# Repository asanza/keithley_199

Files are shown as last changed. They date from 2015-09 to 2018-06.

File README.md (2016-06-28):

# Keithley 199 Digital Board Replacement

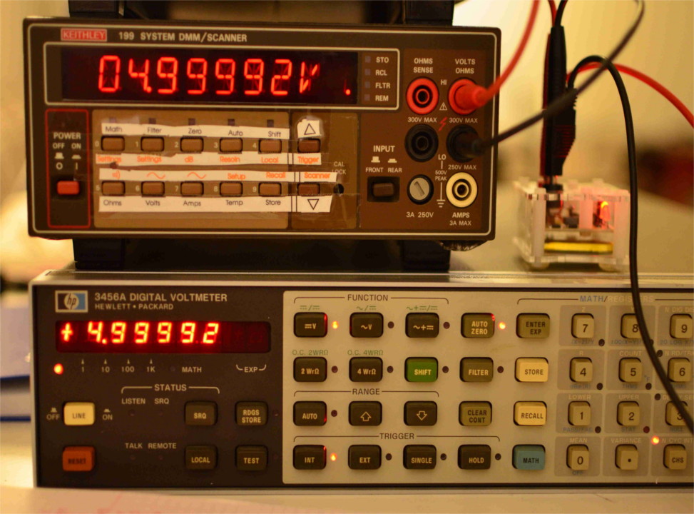
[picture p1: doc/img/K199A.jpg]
keithley 199


This is an upgrade replacement for the digital control board on Keithley 199 multimeters.

The [Keithley 199](doc/k199_op_maint.pdf) is a digital multimeter built in the nineties. It is capable of current, voltage and resistance measurements and also provides a gpib interface for remote control.

These multimeters contains three electronic circuit boards, one which contains the analog circuitry, including analog signal conditioning and analog digital converter, a display board which contains the user interface, and a digital control board, with a processor who controls display, gpib interface and analog digital converter.

This repository contains hardware and software files needed to build a replacement of the digital control board.

# Features
- Voltage Measurement 0.3, 3, 30, 300 VDC/VAC 6.5 digits
- Current Measurement 30mA, 3A DC/AC,  6.5 digits
- Resistance Measurement 300-3GOhm, 6.5 digits, 4 wire.
- Arbitrary integration period
- SCPI interface
- Free Software

# Building the hardware 

The hardware files are in [Kicad](http://kicad-pcb.org/) format. Gerber files are (not yet) available.

# Building the software

The software was built with the [Microchip Toolchain](http://www.microchip.com/mplab/compilers). 

We use [Ceedling](http://www.throwtheswitch.org/ceedling/) for building and testing (but for comfort, [MPLABX](http://www.microchip.com/mplab/mplab-x-ide) files are available). 

In order to build the software, go to the root directory and do:

```
$rake release

```
Or to perform the unit tests:
```
$rake test:all
```

## Hardware

The hardware is pretty basic. It contains a pic32mx controller which do the heavy lifting. An ftdi chip provides an usb interface, while two open drain drivers controll the led displays. The external trigger input and output are connected to the microcontroller through the necessary input/output protection.

## Calibration

TODO

## Principles of Operation

The interesting part is the Control of the analog board. The analog board contains a series of switches that are controlled with a shift register. The adc conversion is performed with a discrete charge-balance adc which returns a pulse train with a pulse count proportional to the input voltage. The control of the adc is performed by the microcontroller in the digital board and should observe a precise timing in order to guarantee adc accuracy.

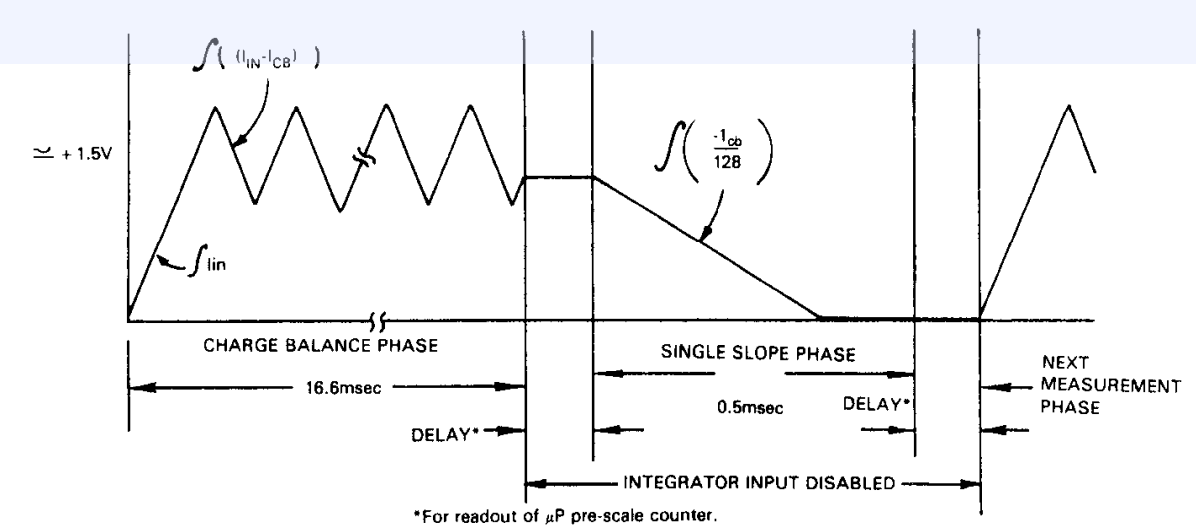
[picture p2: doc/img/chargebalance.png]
charge balance


As shown in the figure above, the charge balance phase starts after the controller sends a start of conversion to the analog board. While the charge balance phase takes place, the controller counts the number of pulses it receives from the analog board. The analog board only send pulses on the up parts, thus the number of pulses is proportional to the charge acumulated. After exactly 16.66 msecs the controller sends an stop of conversion and the single slope phase starts, discharging the integrator. While discharge takes place, the controller counts the number of pulses received.

# Licence

```
 * Copyright (c) 2015, Diego F. Asanza. All rights reserved.
 *
 * This software is free software; you can redistribute it and/or
 * modify it under the terms of the GNU Lesser General Public
 * License as published by the Free Software Foundation; either
 * version 2.1 of the License, or (at your option) any later version.
 *
 * This library is distributed in the hope that it will be useful,
 * but WITHOUT ANY WARRANTY; without even the implied warranty of
 * MERCHANTABILITY or FITNESS FOR A PARTICULAR PURPOSE.  See the GNU
 * Lesser General Public License for more details.
 *
 * You should have received a copy of the GNU Lesser General Public
 * License along with this library; if not, write to the Free Software
 * Foundation, Inc., 51 Franklin Street, Fifth Floor, Boston,
 * MA 02110-1301  USA
 *
 ```

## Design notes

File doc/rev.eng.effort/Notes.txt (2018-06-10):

Data is shifted in Positive clock Transitions. (It means data is valid on trailing edge (negative transition)
Data is received INVERTED in analog board (the optocoupler inverts).
Strobe shifts data to out. Strobe is also inverted in analog board.

5 bytes are sended each time (there are 5 shift registers, four on analog board and one on scanner card.). The last byte controls the analog digital converter.

Last Register Bits: (Digital Board)
Seq.	Q8	Q7	Q6	Q5		Q4	Q3		Q2	Q1	Time
	/Cal	/Zero	Fast	/ReadSwitch	Sig	/FinalSlope	Sync	Int
0x95	1	0	0	1		0	1		0	1	6m  // Start integration
0x94	1	0	0	1		0	1		0	0	20m // end integration
0x92	1	0	0	1		0	0		1	0	0   // Rundown slope	

0x55	0	1	0	1		0	1		0	1	6m  // Start Integration
0x54	0	1	0	1		0	1		0	0	20m  // end integration
0x52	0	1	0	1		0	0		1	0	800u // Rundown slope

Cal: When 0 is the reference connected to the A/D
Zero: When 0  the multiplexer selects ground for input to the A/D
Fast:
ReadSwitch: When 0 in Analog board, the position of front/rear switch is readed (-4.3 and volts/ohms lo)
Sig: When 1 in analog board, 3V signal direct to A/D
/FinalSlope:	Starts the Rundown slope integration
Sync: Resets AD Clocks
Int: (Start Conversion)

The conversion sequence is as follows. 

- Integration Vin
- Integration Vin Zero
- Integration Vref
- Integration Vref Zero

Vout = -2.8*(Vin - VinZero)/(Vref - VrefZero)

30 V requeriments requerew a separate zero

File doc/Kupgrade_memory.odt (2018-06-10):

Keithley Repair memory

Start: 12 March 2014

Recently I bought an old Keithley 199 multimeter in an auction at e-bay. It didn't work, but it was cheap. Further analysis showed an error on the digital board. The VIA (peripheral controller) was broken.

I know, I could bough a new via (they are no more produced, I think, but they are still available from resellers on e-bay). But, as an engineer, that solution wasn't satisfactory. I wanted to bring the old multimeter to new standards (at least in the digital side). So with a lot of naivety, I decided to replace the broken board with my own creation.

Actually, the good think with old measurement equipment, is that almost all good manufacturers published pretty detailed service manuals, schematic inclusive. Paraphrasing Feynman, to have the map of the cat is the best form to start.

The Digital interface couldn't be more simple. In order to reduce the number of control lines between digital and analog boards, the Keithley 199 uses a serial interface. Pretty basic, nothing to fancy like spi or i2c. Three control lines go from digital to analog board and one goes back into the digital world. The firs three are serial data which are clocked into shift registers in the analog board, which in turn, control the different switch for range selection, ohms measurements, and analog digital conversion. The line which goes back provides the digital value of the analog signal, the output of the analog digital converter.

Well, this in theory. Now it is time to go into the finer details. One thing, which I personally find fascinating, is that the analog digital converter is actually implemented with discrete parts, and actually controlled from the processor. Nowadays this is no more done, as there is frequently a custom ASIC or an FPGA who does the control of the integrating analog digital converter.

The analog digital converter is from the charge-balancing variety. In order to explain how it works, may be is easier to start with a close cousin, the double ramp integrating analog to digital converter.

The double ramp integrating converter, as it name hints, works integrating the unknown voltage for a fixed amount of time, and then discharging the integration capacitor connecting a reference voltage of opposite polarity and measuring the time the output of the integrator takes to reach zero. This process is shown graphically on figure x. It shows a basic integrator circuit where the voltage output ramps up as function of the unknow voltage and time. The relationship between unknown voltage and time is given by following formula:

In the ramp down part, an know reference voltage, of reverse polarity as the input signal, is connected to the input. The output voltaje ramps down until it reach zero. The output voltage during this ramp down period is given by following formula:

Relating equations 1 and 2, we can calculate the input voltage as function of the time passed between start of the ramp up period and end of the ramp down period:

Easy, isn't it. At least in theory. But as always the devil is in the details. We will talk about this in a moment.

The double ramp converter is easy to implement, and as we can see in formula x, it is almost independent of the actual phisical components. And I say almost, because even thought the values of the components are left out of the equation, this equation assumes ideal integrator behavior in first place. And, oh surprise, it is not!.

The first problem is related to the limited supply voltage. The integrator is, of course, an electronic circuit, and it needs to get its supply voltage from somewhere. If we let connected the unknown voltage at the input of the integrator (see figure x), the output voltage will ramp-up but only until the output voltage reaches nearly the supply voltage, a situation know as saturation.

The second problem comes from the integrating capacitor. I know, it comes a little bit of a surprise, because there is no capacitor in the equation for the output voltage (eq. y), but remember from which equations it comes from:

1 y 2

Did you see?. When you equal these two equations in order to get the output voltage, you make the assumption that the capacitor in the interval one is the same that is on interval two, and it is not always the case. Due to a phenomenon know as “Dielectric absorption”, the capacitor will change its behavior with time.

Here comes the charge balancing in the game. Charge balancing works similar as double slope, first an unknown voltage is integrated, but instead of let the output go indefinite up, a circuit compares the output and when it reaches a defined level, and then, a reference voltage is applied in the input which causes the output to ramp down. When the output voltage has ramp down for a little while, we disconnect again the reference voltage, which causes the output to ramp up again, as the unknown voltage is still present in the input. If we track carefully how much time has the output voltage ramped down, we can also calculate the unknown input voltage.

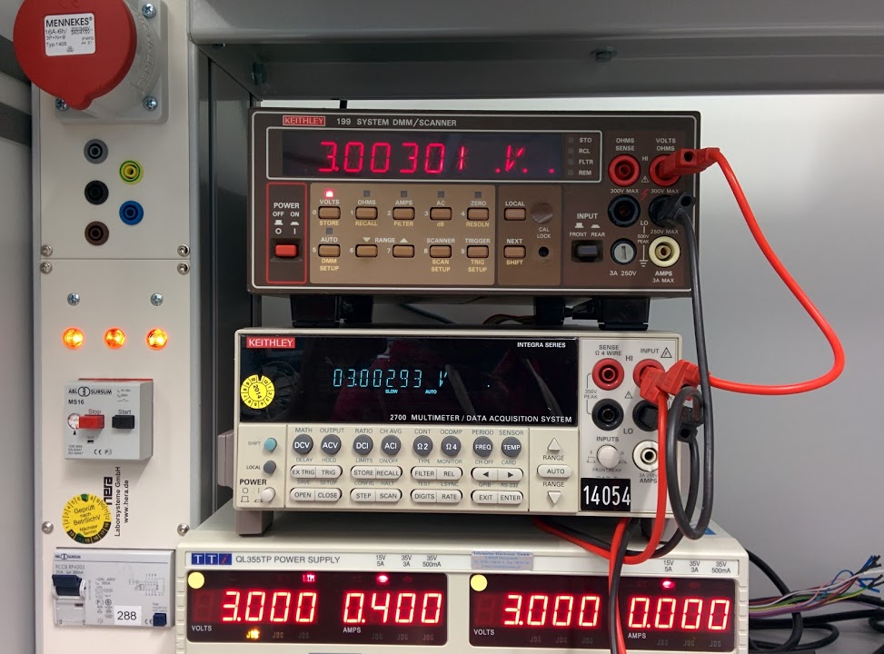
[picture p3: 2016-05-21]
doc/img/K199_back.jpg

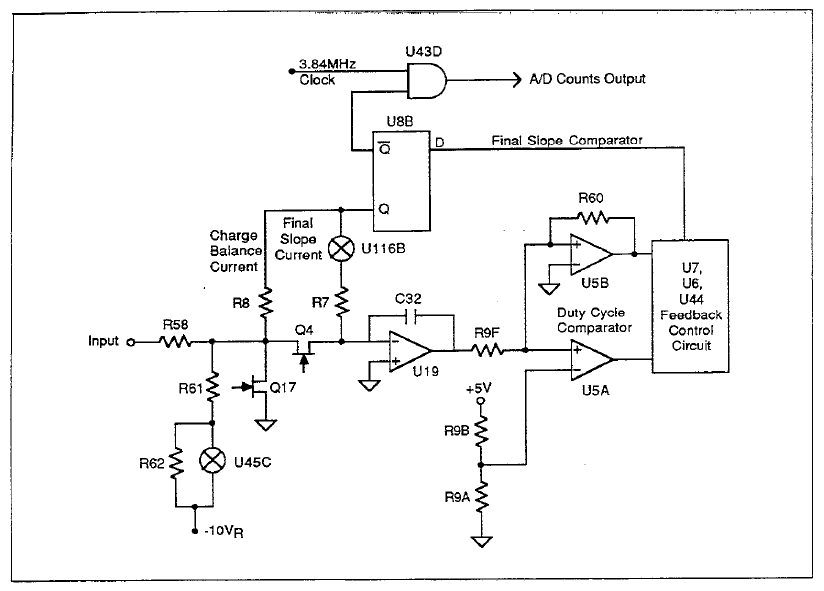
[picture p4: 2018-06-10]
doc/keithley_adc_sch.png

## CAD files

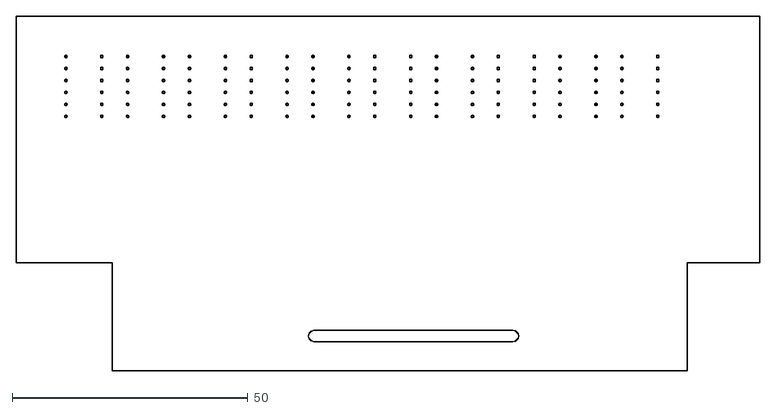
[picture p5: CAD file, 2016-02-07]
hw.kicad/frontpanel/frontpanel.dxf
157.7 x 75.2

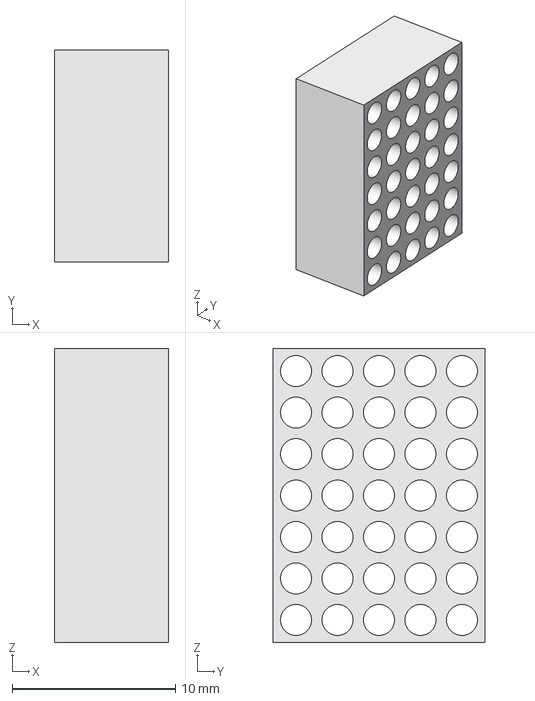
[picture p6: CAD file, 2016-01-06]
hw.kicad/frontpanel/LedMatrix.fcstd
7.00 x 13.0 x 18.0 mm

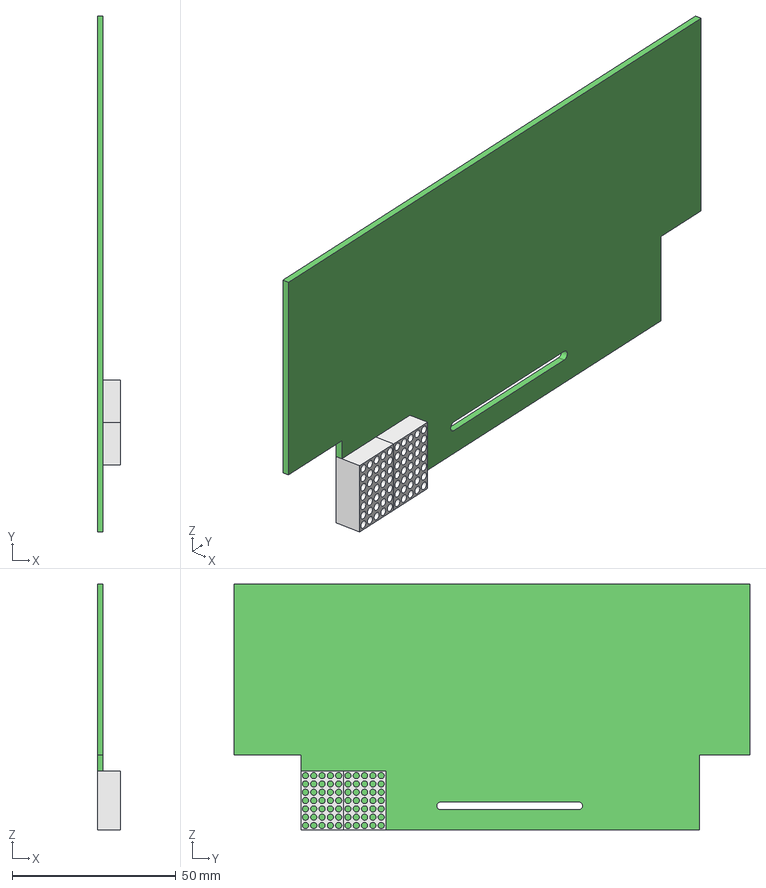
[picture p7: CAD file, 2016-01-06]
hw.kicad/frontpanel/frontdesign.fcstd
7.00 x 157.7 x 75.2 mm
pcb

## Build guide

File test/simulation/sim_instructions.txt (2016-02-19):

device pic32MX350F256H
hwtool sim
set oscillator.auxfrequency 	120
set oscillator.auxfrequencyunit Mega
set oscillator.frequency 	100
set oscillator.frequencyunit 	Mega
set oscillator.rcfrequency  	250
set oscillator.rcfrequencyunit 	Kilo
set uart2io.uartioenabled	true
set uart2io.output		file
set uart2io.outputfile		test/simulation/out.txt
set system.disableerrormsg 	true

program build/test/TestBuild.elf

run
break unity.c:1168
wait 20000
quit

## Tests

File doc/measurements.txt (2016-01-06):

#2015-12-08 09:43:34.418110
1; +0.2499589E+01; +02.49944E+0; 0.000149
2; +0.2499550E+01; +02.49940E+0; 0.00015
3; +0.2499591E+01; +02.49949E+0; 0.000101
4; +0.2499580E+01; +02.49943E+0; 0.00015
5; +0.2499571E+01; +02.49944E+0; 0.000131
6; +0.2499570E+01; +02.49943E+0; 0.00014
7; +0.2499559E+01; +02.49943E+0; 0.000129
8; +0.2499611E+01; +02.49943E+0; 0.000181
9; +0.2499579E+01; +02.49945E+0; 0.000129
10; +0.2499560E+01; +02.49942E+0; 0.00014
11; +0.2499571E+01; +02.49944E+0; 0.000131
12; +0.2499582E+01; +02.49943E+0; 0.000152
13; +0.2499551E+01; +02.49944E+0; 0.000111
14; +0.2499601E+01; +02.49944E+0; 0.000161
15; +0.2499583E+01; +02.49944E+0; 0.000143
16; +0.2499602E+01; +02.49945E+0; 0.000152
17; +0.2499581E+01; +02.49946E+0; 0.000121
18; +0.2499560E+01; +02.49943E+0; 0.00013
19; +0.2499601E+01; +02.49945E+0; 0.000151
20; +0.2499591E+01; +02.49942E+0; 0.000171
21; +0.2499540E+01; +02.49943E+0; 0.00011
22; +0.2499590E+01; +02.49946E+0; 0.00013
23; +0.2499590E+01; +02.49944E+0; 0.00015
24; +0.2499541E+01; +02.49942E+0; 0.000121
25; +0.2499570E+01; +02.49942E+0; 0.00015
26; +0.2499572E+01; +02.49945E+0; 0.000122
27; +0.2499570E+01; +02.49944E+0; 0.00013
28; +0.2499571E+01; +02.49946E+0; 0.000111
29; +0.2499571E+01; +02.49946E+0; 0.000111
30; +0.2499560E+01; +02.49946E+0; 9.99999999998e-05
31; +0.2499571E+01; +02.49943E+0; 0.000141
32; +0.2499559E+01; +02.49946E+0; 9.90000000001e-05
33; +0.2499572E+01; +02.49948E+0; 9.2e-05
34; +0.2499571E+01; +02.49945E+0; 0.000121
35; +0.2499582E+01; +02.49942E+0; 0.000162
36; +0.2499582E+01; +02.49941E+0; 0.000172
37; +0.2499593E+01; +02.49941E+0; 0.000183
38; +0.2499593E+01; +02.49942E+0; 0.000173
39; +0.2499591E+01; +02.49939E+0; 0.000201
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

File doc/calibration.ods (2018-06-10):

Ref | Test | a | b | corrected
0.004 | 0.000136 | 0.0283305456 | 0.003996147 | 0.004
0.6 | 21.0375 |  |  | 0.6

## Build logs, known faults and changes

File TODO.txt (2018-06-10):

- Revisar FTDI Pinout (which type??)
- Look out for a LDO 3.3V (http://www.ti.com/lit/ds/symlink/lm2936.pdf)
- Xtal (8MHz) footprint (type, condensators)    //DONE
- EEPROM (Need code)                            
- Display drivers (or transistors)              
- Trigger Input and Voltmeter complete (outputs) voltmeter complete can be used for other signals also (square wave, pulse, pwm, etc)
- Look for resistor networks (80 and 4k7 (10k))
- Look for ftdi circuit

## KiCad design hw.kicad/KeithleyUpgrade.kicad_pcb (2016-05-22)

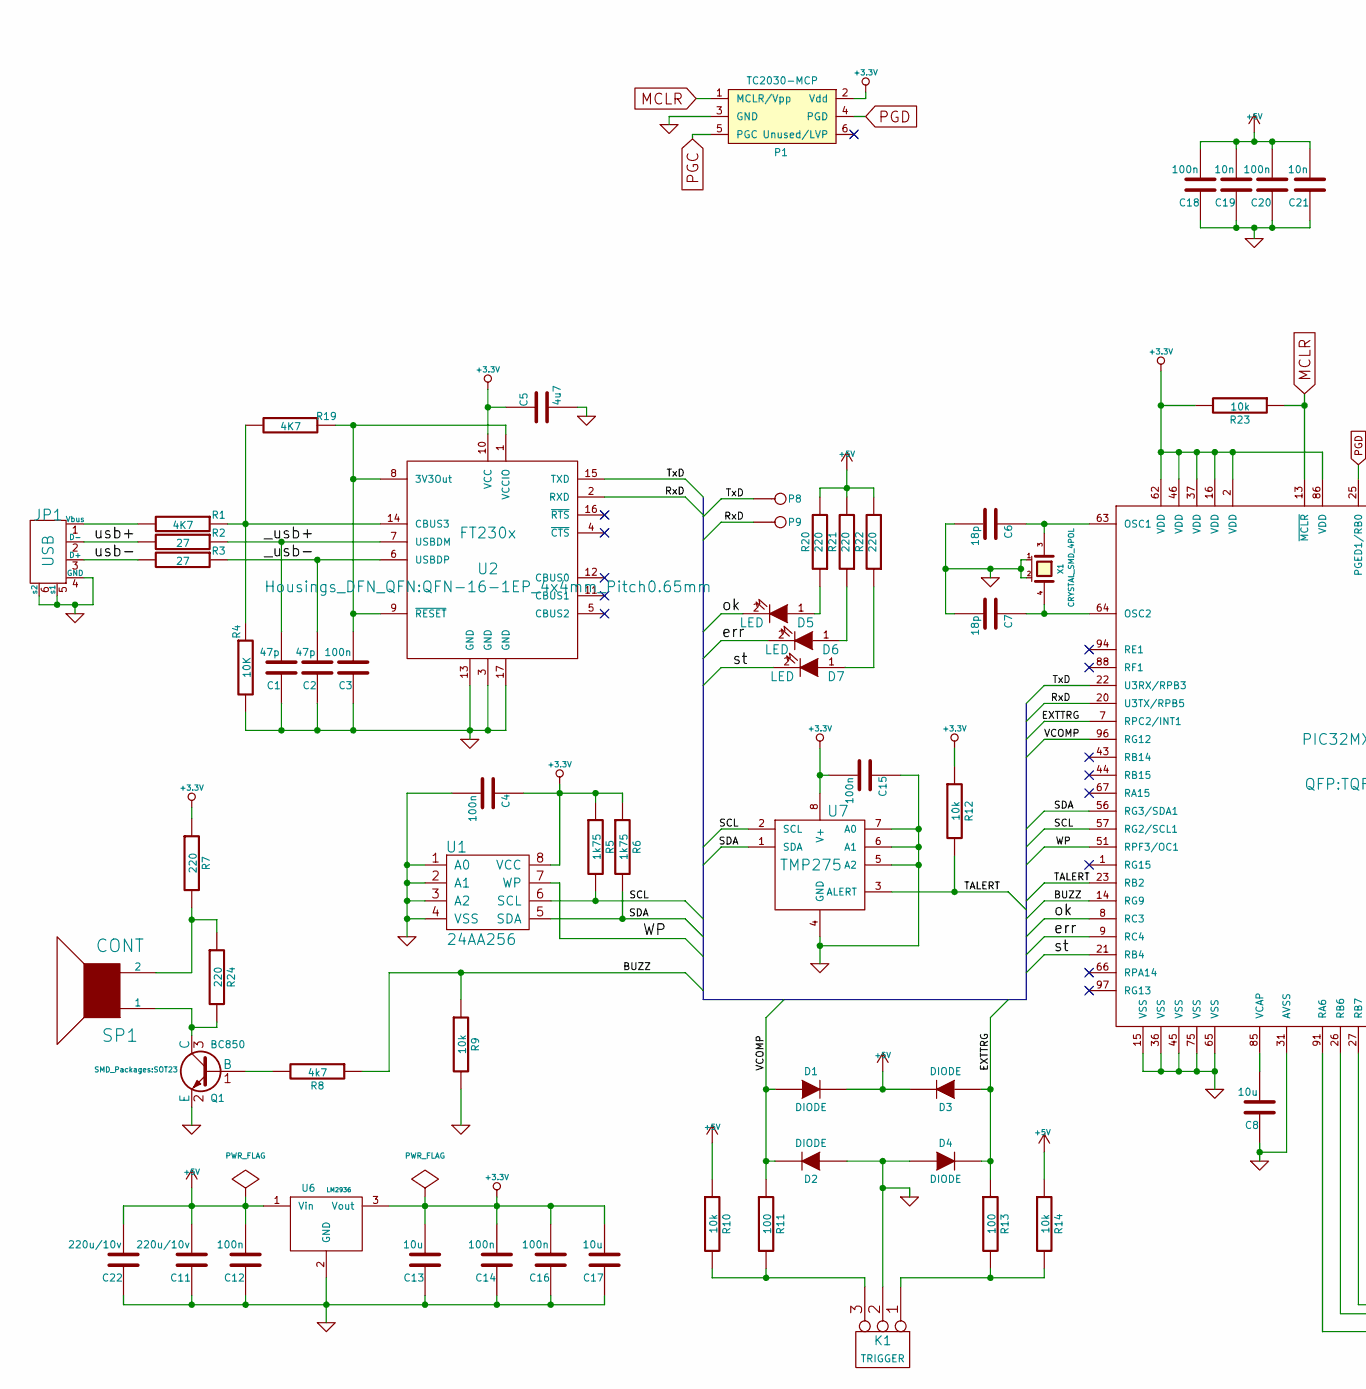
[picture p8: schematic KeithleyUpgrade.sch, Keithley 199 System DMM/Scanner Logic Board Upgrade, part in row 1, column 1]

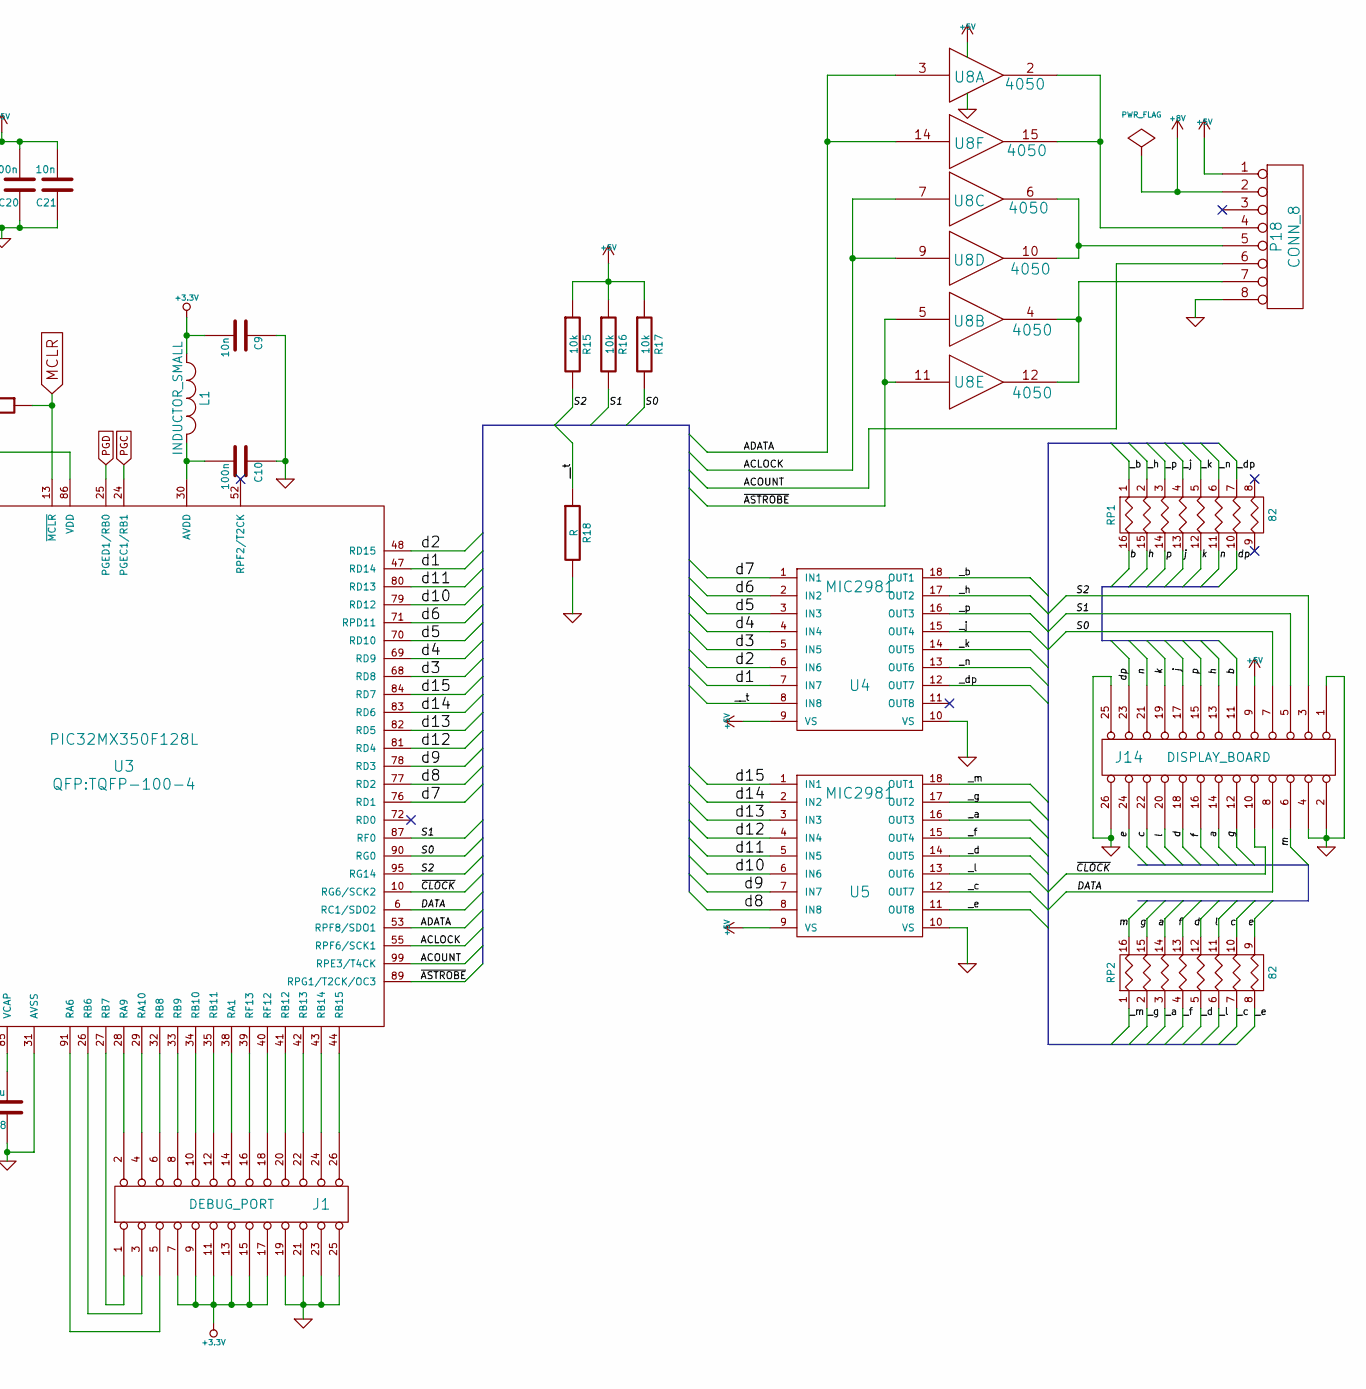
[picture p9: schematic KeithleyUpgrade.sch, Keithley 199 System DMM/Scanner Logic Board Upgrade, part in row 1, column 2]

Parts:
C1, C2: 47p; C_0805
C3, C4, C10, C12, C14, C15, C16, C18, C20: 100n; C_0805
C5: 4u7; C_1206
C6, C7: 18p; C_0805
C8: 10u; C_0805
C9, C19, C21: 10n; C_0805
C11, C22: 220u/10v; c_elec_10x10
C13, C17: 10u; C_1210
D1, D2, D3, D4: DIODE; Diode-SMA_Standard
D5, D6, D7: LED; LED-0805
J1: DEBUG_PORT; header_straight_2x13
J14: DISPLAY_BOARD; header_straight_2x13
JP1: USB; USB_B
K1: TRIGGER; bornier3
L1: INDUCTOR_SMALL; SMD-1210
P1: TC2030-MCP; TC2030-NL_SMALL
P8, P9: TP1; SIL-1
P18: CONN_8; Pin_Header_Straight_1x08
Q1: BC850; SOT23
R1: 4K7; SM0805
R2, R3: 27; SM0805
R4: 10K; SM0805
R5, R6: 1k75; SM0805
R7: 220; SM0805
R8: 4k7; SM0805
R9, R10, R12, R14, R15, R16, R17, R23: 10k; R_0805
R11, R13: 100; R_0805
R18: R; R_0805
R19: 4K7; R_0805
R20, R21, R22, R24: 220; R_0805
RP1, RP2: 82; SOM16
SP1: CONT; Elko_vert_DM14_RM5
U1: 24AA256; SOIC-8_N
U2: FT230x; QFN-16-1EP_4x4mm_Pitch0.65mm
U3: PIC32MX350F128L; TQFP-100-4
U4, U5: MIC2981; soic-18
U6: LM2936; DPAK2
U7: TMP275; SOIC-8_N
U8: 4050; SOIC-16_Narrow
X1: CRYSTAL_SMD_4POL; XTAL_SMD_5x3_2

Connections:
/ACLOCK: U3.55 (RPF6/SCK1), U8.7, U8.9
/ACOUNT: P18.6, U3.99 (RPE3/T4CK)
/ADATA: U3.53 (RPF8/SDO1), U8.3, U8.14
/BUZZ: R8.1, R9.1, U3.14 (RG9)
/DATA: J14.8, U3.6 (RC1/SDO2)
/EXTTRG: D3.1 (A), D4.2 (K), R13.1, U3.7 (RPC2/INT1)
/RxD: P9.1, U2.2 (RXD), U3.20 (U3TX/RPB5)
/S0: J14.7, R17.2, U3.90 (RG0)
/S1: J14.5, R16.2, U3.87 (RF0)
/S2: J14.3, R15.2, U3.95 (RG14)
/SCL: R5.2, U1.6 (SCL), U3.57 (RG2/SCL1), U7.2 (SCL)
/SDA: R6.2, U1.5 (SDA), U3.56 (RG3/SDA1), U7.1 (SDA)
/TALERT: R12.2, U3.23 (RB2), U7.3 (ALERT)
/TxD: P8.1, U2.15 (TXD), U3.22 (U3RX/RPB3)
/VCOMP: D1.1 (A), D2.2 (K), R11.1, U3.96 (RG12)
/WP: U1.7 (WP), U3.51 (RPF3/OC1)
/__t: R18.1, U4.8 (IN8)
/_a: RP2.3, U5.16 (OUT3)
/_b: RP1.1, U4.18 (OUT1)
/_c: RP2.7, U5.12 (OUT7)
/_d: RP2.5, U5.14 (OUT5)
/_dp: RP1.7, U4.12 (OUT7)
/_e: RP2.8, U5.11 (OUT8)
/_f: RP2.4, U5.15 (OUT4)
/_g: RP2.2, U5.17 (OUT2)
/_h: RP1.2, U4.17 (OUT2)
/_j: RP1.4, U4.15 (OUT4)
/_k: RP1.5, U4.14 (OUT5)
/_l: RP2.6, U5.13 (OUT6)
/_m: RP2.1, U5.18 (OUT1)
/_n: RP1.6, U4.13 (OUT6)
/_p: RP1.3, U4.16 (OUT3)
/_usb+: C1.2, R2.1, U2.7 (USBDM)
/_usb-: C2.2, R3.1, U2.6 (USBDP)
/a: J14.14, RP2.14 (R3)
/b: J14.11, RP1.16 (R1)
/c: J14.22, RP2.10 (R7)
/d: J14.18, RP2.12 (R5)
/d1: U3.47 (RD14), U4.7 (IN7)
/d2: U3.48 (RD15), U4.6 (IN6)
/d3: U3.68 (RD8), U4.5 (IN5)
/d4: U3.69 (RD9), U4.4 (IN4)
/d5: U3.70 (RD10), U4.3 (IN3)
/d6: U3.71 (RPD11), U4.2 (IN2)
/d7: U3.76 (RD1), U4.1 (IN1)
/d8: U3.77 (RD2), U5.8 (IN8)
/d9: U3.78 (RD3), U5.7 (IN7)
/d10: U3.79 (RD12), U5.6 (IN6)
/d11: U3.80 (RD13), U5.5 (IN5)
/d12: U3.81 (RD4), U5.4 (IN4)
/d13: U3.82 (RD5), U5.3 (IN3)
/d14: U3.83 (RD6), U5.2 (IN2)
/d15: U3.84 (RD7), U5.1 (IN1)
/dp: J14.23, RP1.10 (R7)
/e: J14.24 (P20), RP2.9 (R8)
/err: D6.2 (K), U3.9 (RC4)
/f: J14.16, RP2.13 (R4)
/g: J14.12, RP2.15 (R2)
/h: J14.13, RP1.15 (R2)
/j: J14.17, RP1.13 (R4)
/k: J14.19, RP1.12 (R5)
/l: J14.20, RP2.11 (R6)
/m: J14.6, RP2.16 (R1)
/n: J14.21, RP1.11 (R6)
/ok: D5.2 (K), U3.8 (RC3)
/p: J14.15, RP1.14 (R3)
/st: D7.2 (K), U3.21 (RB4)
/usb+: JP1.2 (D-), R2.2
/usb-: JP1.3 (D+), R3.2
/~ASTROBE: U3.89 (RPG1/T2CK/OC3), U8.5, U8.11
/~CLOCK: J14.10, U3.10 (RG6/SCK2)
GND: C1.1, C2.1, C3.1, C4.2, C5.2, C6.2, C7.2, C8.1, C9.1, C10.1, C11.1, C12.1, C13.1, C14.1, C15.1, C16.1, C17.1, C18.1, C19.1, C20.1, C21.1, C22.1, D2.1 (A), D4.1 (A), J1.19, J1.21, J1.23, J1.25 (P24), J14.1, J14.2, J14.4, J14.25 (P24), J14.26 (P22), JP1.4 (GND), JP1.5 (s1), JP1.6 (s2), K1.2 (PM), P1.3 (GND), P18.8, Q1.2 (E), R4.2, R9.2, R18.2, U1.1 (A0), U1.2 (A1), U1.3 (A2), U1.4 (VSS), U2.3 (GND), U2.13 (GND), U2.17 (GND), U3.15 (VSS), U3.31 (AVSS), U3.36 (VSS), U3.45 (VSS), U3.65 (VSS), U3.75 (VSS), U4.10 (VS), U5.10 (VS), U6.2 (GND), U7.4 (GND), U7.5 (A2), U7.6 (A1), U7.7 (A0), U8.8 (VSS), X1.1 (case), X1.2 (case)
MCLR: P1.1 (MCLR/Vpp), R23.1, U3.13 (~MCLR)
unnamed: C3.2, R19.1, U2.1 (VCCIO), U2.8 (3V3Out), U2.9 (~RESET)
unnamed: C6.1, U3.63 (OSC1), X1.3
unnamed: C7.1, U3.64 (OSC2), X1.4
unnamed: C8.2, U3.85 (VCAP)
unnamed: C10.2, L1.2, U3.30 (AVDD)
unnamed: D5.1 (A), R20.1
unnamed: D6.1 (A), R21.1
unnamed: D7.1 (A), R22.1
unnamed: J1.1, U3.27 (RB7)
unnamed: J1.2, U3.28 (RA9)
unnamed: J1.3, U3.26 (RB6)
unnamed: J1.4, U3.29 (RA10)
unnamed: J1.5, U3.91 (RA6)
unnamed: J1.6, U3.32 (RB8)
unnamed: J1.8, U3.33 (RB9)
unnamed: J1.10, U3.34 (RB10)
unnamed: J1.12, U3.35 (RB11)
unnamed: J1.14, U3.38 (RA1)
unnamed: J1.16, U3.39 (RF13)
unnamed: J1.18, U3.40 (RF12)
unnamed: J1.20, U3.41 (RB12)
unnamed: J1.22, U3.42 (RB13)
unnamed: JP1.1 (Vbus), R1.2
unnamed: K1.1, R13.2, R14.2
unnamed: K1.3, R10.2, R11.2
unnamed: P18.4, U8.2, U8.15
unnamed: P18.5, U8.6, U8.10
unnamed: P18.7, U8.4, U8.12
unnamed: Q1.1 (B), R8.2
unnamed: Q1.3 (C), R24.2, SP1.1
unnamed: R1.1, R4.1, R19.2, U2.14 (CBUS3)
unnamed: R7.2, R24.1, SP1.2
PGC: P1.5 (PGC), U3.24 (PGEC1/RB1)
PGD: P1.4 (PGD), U3.25 (PGED1/RB0)

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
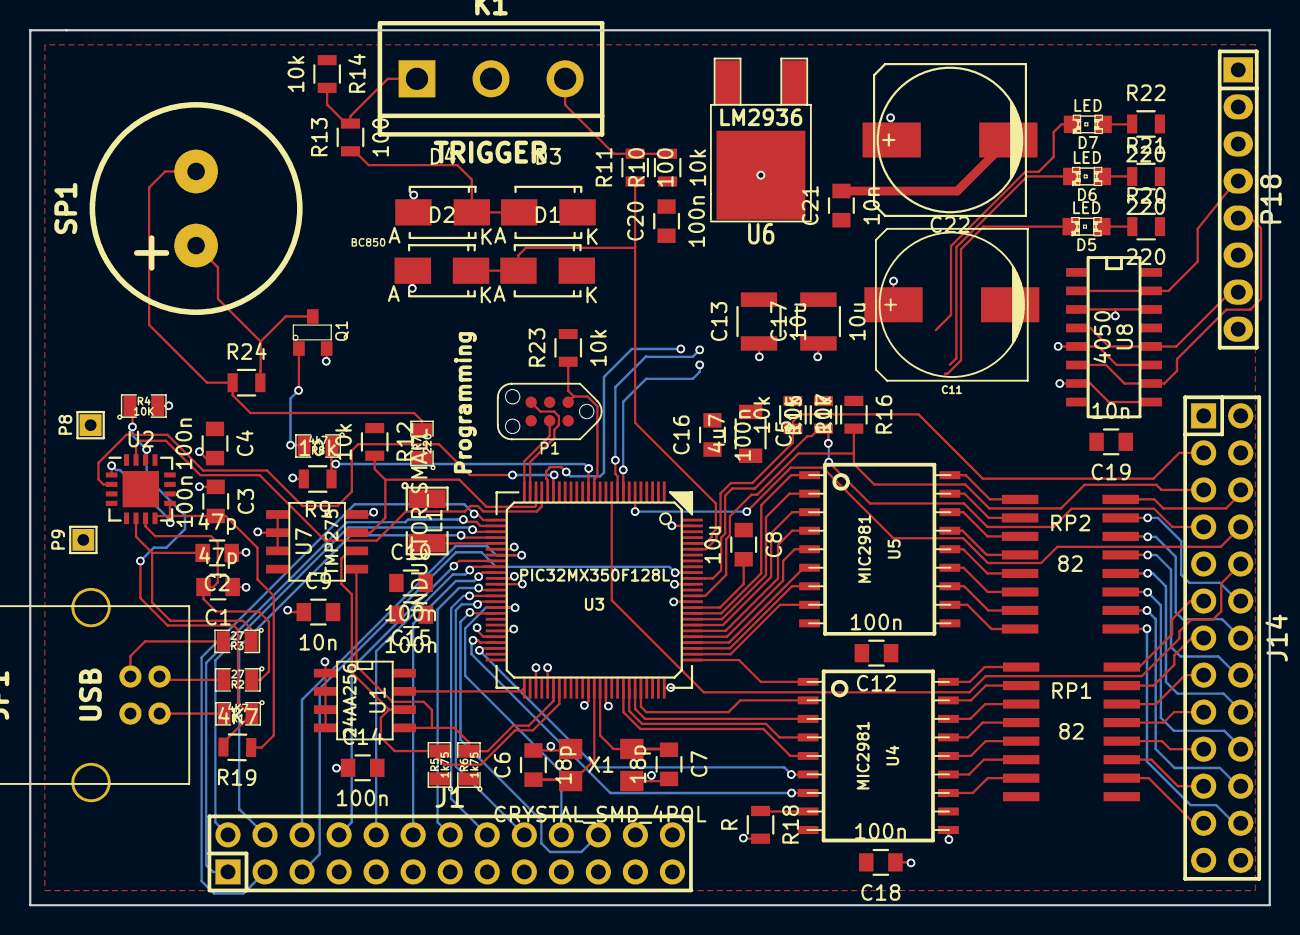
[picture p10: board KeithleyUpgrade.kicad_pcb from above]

Board: 4 copper layers, 85.0 x 60.0 mm, 75 parts (0 on the bottom side), 109 nets.

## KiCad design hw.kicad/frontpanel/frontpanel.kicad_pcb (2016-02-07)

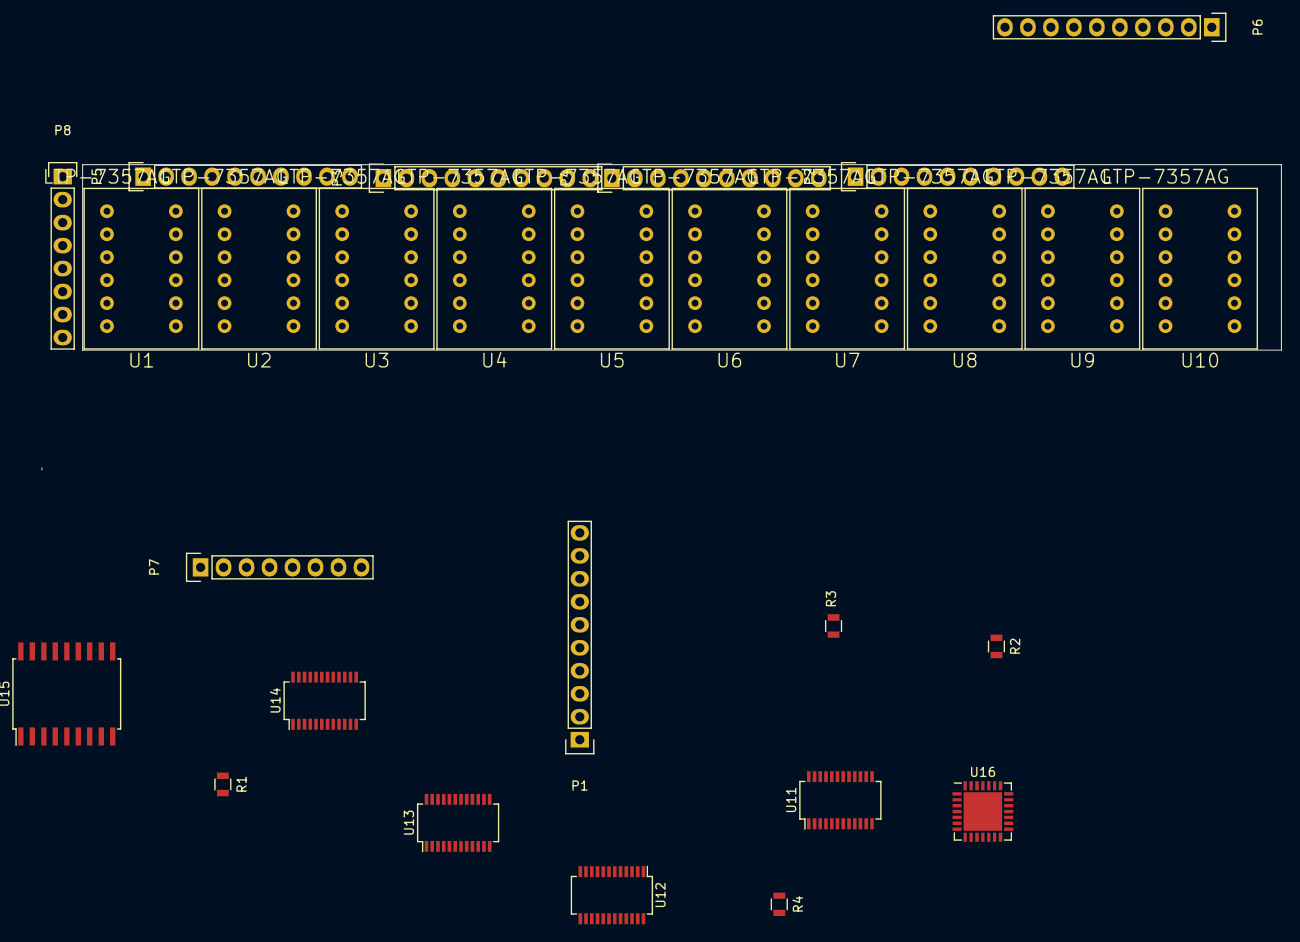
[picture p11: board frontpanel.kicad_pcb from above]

Board: 2 copper layers, 28 parts (0 on the bottom side), 19 nets, no tracks yet.

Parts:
P1, P2, P3, P4, P5, P6: CONN_10; Pin_Header_Straight_1x10
P7, P8: CONN_8; Pin_Header_Straight_1x08
R1, R2, R3, R4: R; R_0805
U1, U2, U3, U4, U5, U6, U7, U8, U9, U10: LTP-7357AG
U11, U12, U13, U14: TLC5928; SSOP-24_3.9x8.7mm_Pitch0.635mm
U15: MIC2981; SOIC-18_7.5x11.6mm_Pitch1.27mm
U16: DSPIC33FJ64GP802; QFN-28-1EP_6x6mm_Pitch0.65mm

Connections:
/ROW1: U1.12, U2.12, U3.12, U4.12, U5.12, U6.12, U7.12, U8.12, U9.12, U10.12
/ROW2: U1.11, U2.11, U3.11, U4.11, U5.11, U6.11, U7.11, U8.11, U9.11, U10.11
/ROW3: U1.2, U2.2, U3.2, U4.2, U5.2, U6.2, U7.2, U8.2, U9.2, U10.2
/ROW4: U1.9, U2.9, U3.9, U4.9, U5.9, U6.9, U7.9, U8.9, U9.9, U10.9
/ROW5: U1.4, U2.4, U3.4, U4.4, U5.4, U6.4, U7.4, U8.4, U9.4, U10.4
/ROW6: U1.5, U2.5, U3.5, U4.5, U5.5, U6.5, U7.5, U8.5, U9.5, U10.5
/ROW7: U1.6, U2.6, U3.6, U4.6, U5.6, U6.6, U7.6, U8.6, U9.6, U10.6
GND: R1.2, R2.2, R3.2, R4.2, U11.1, U12.1, U13.1, U14.1, U15.10
unnamed: R1.1, U14.23
unnamed: R2.1, U11.23
unnamed: R3.1, U12.23
unnamed: R4.1, U13.23
unnamed: U11.2, U12.22
unnamed: U11.3, U12.3, U13.3, U14.2
unnamed: U11.4, U12.4, U13.4, U14.3
unnamed: U11.21, U12.21, U13.21, U14.4
unnamed: U12.2, U13.22
unnamed: U13.2, U14.22
VCC: U11.24, U12.24, U13.24, U14.24, U15.9

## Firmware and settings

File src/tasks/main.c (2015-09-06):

#include <stdio.h>
#include <diag.h>
#include <FreeRTOS.h>
#include <task.h>
#include <assert.h>
#include <system.h>
#include <diag.h>
#include "tskmgr.h"

int main()
{
    /* hardware initialization. An error here is unrecoverable */
    system_init();
    /* start tasks as needed */
    taskmgr_start();
    DIAG("START: %s, %s", REPOVERSION, REPOBRANCH);
    DIAG("Starting Scheduler");
    vTaskStartScheduler();
    return 0;
}

void vAssertCalled(const char* fileName, unsigned long lineNo)
{
    DIAG("FreeRTOS: %s, %ld\n", fileName, lineNo);
    while (1);
}

void vApplicationIdleHook(void)
{
    hal_sys_idle();
}

void vApplicationStackOverflowHook(TaskHandle_t pxTask, signed char *pcTaskName)
{
    DIAG("%s", pcTaskName);
    assert(0);
    while (1);
}

void vApplicationMallocFailedHook()
{
    DIAG("");
    assert(0);
    while (1);
}

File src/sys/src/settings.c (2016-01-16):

/*
 * store.c
 *
 * Copyright (c) 2015, Diego F. Asanza. All rights reserved.
 *
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
 * Created on July 15, 2015, 10:39 PM
 */

#include "settings.h"
#include <eefs.h>
#include <stdbool.h>

#include "adcctrl.h"
#include <FreeRTOS.h>
#include "semphr.h"
#include "portmacro.h"
#include <assert.h>
#include <string.h>
#include <diag.h>
#include <math.h>
#include <adcdefs.h>

typedef struct _settings_t{
    adc_input               input               :4 ; /* settings name */
    adc_channel             channel             :8 ; /* which channel is selected on the scanner */
    adc_integration_period  integration_period  :16; /* integration period used */
    adc_range               range               :4 ; /* selected range */
    adc_resolution          resn                :3 ;
    bool                    auto_range          :1 ; /* auto_range selected */
    bool                    filter_enabled      :1 ; /* filter */
    uint8_t                 filter_resoln       :8 ; /* filter resolution */
    conv_func               math;                    /* selected math function */
    out_fmt                 formatter;               /* selected output format */
} __attribute__((__packed__)) settings_t;

typedef struct _calibration_t{
    double gain;
    double offset;
    double temp;
}calibration_t;

#define SETTINGS_START_ADDRESS  0x0A
static calibration_t cal;

SemaphoreHandle_t slock = NULL;

static void lock(void){
    xSemaphoreTake(slock, portMAX_DELAY);
}

static void unlock(void){
    xSemaphoreGive(slock);
}

/* each input has its settings */
static settings_t settings[ADC_NUMBER_OF_INPUTS];
static settings_t* actual_settings = settings;

static void settings_set_default();

void settings_init(void){
    if(!slock){
        slock = xSemaphoreCreateMutex();
    }
    int i;    
    for (i = 0; i < ADC_NUMBER_OF_INPUTS; i++) {
        settings_set_default();
    }
    cal.gain = 1;
    cal.offset = 0;
    cal.temp = 25;
}

void settings_save(settings_location location){
    lock();
    int i;
    int addr = SETTINGS_START_ADDRESS + location*sizeof(settings);
    for(i = 0; i < ADC_NUMBER_OF_INPUTS; i++)
        eefs_object_save(addr + i,&settings[i], sizeof(settings_t));
    eefs_object_save(addr + i, &actual_settings, sizeof(settings_t*));
    unlock();
}

adc_resolution settings_get_resolution(){
    adc_resolution res;
    lock();
    res = actual_settings->resn;
    unlock();
    return res;
}

void settings_set_resolution(adc_resolution res){
    lock();
    if(actual_settings->input == ADC_INPUT_TEMP) 
        actual_settings->resn = ADC_RESOLUTION_5_5;
    else
        actual_settings->resn = res;
    unlock();
}


int settings_restore(settings_location location) {
    int i;
    lock();
    EEFS_ERROR err;
    DIAG(" %d\n", 0);
    int addr = SETTINGS_START_ADDRESS + location * sizeof (settings);
    for (i = 0; i < ADC_NUMBER_OF_INPUTS; i++) {
        err = eefs_object_restore(addr + i, &settings[i], sizeof (settings_t));
        DIAG("iperiod: %d", settings[i].integration_period);
        if (err != EEFS_OK) {
            DIAG("error loading settings");
            settings_set_default();
            unlock();
            return 1;
        }
    }
    actual_settings = settings;
    DIAG("");
//    err = eefs_object_restore(addr + i, &actual_settings, sizeof(settings_t*));
//    if(err != EEFS_OK){
//        actual_settings = settings;
//        DIAG("error loading actual setting");
//    }
    unlock();
    return 0;
}

adc_integration_period settings_get_integration_period(){
    adc_integration_period p;
    lock();
    p = actual_settings->integration_period;
    unlock();
    return p;
}

adc_input settings_get_input(){
    adc_input p;
    lock();
    p = actual_settings->input;
    unlock();
    return p;
}

adc_range settings_get_range(){
    adc_range r;
    lock();
    r = actual_settings->range;
    unlock();
    return r;
}

adc_channel settings_get_channel(){
    lock();
    adc_channel c = actual_settings->channel;
    unlock();
    return c;
}

void settings_set_input(adc_input input){
    assert(input < ADC_NUMBER_OF_INPUTS);
    lock();
    actual_settings = &settings[input];
    unlock();
}

void settings_range_up(void){
    lock();
    if(actual_settings->input == ADC_INPUT_TEMP){
        unlock();
        return;
    }
    /* get the next range for this input */
    adc_range range = adcctrl_get_next_range(actual_settings->input, actual_settings->range);
    if(range == actual_settings->range){
        unlock();
        return;
    }
    actual_settings->range = range;
    unlock();
}

void settings_range_down(void){
    lock();
    if(actual_settings->input == ADC_INPUT_TEMP){
        unlock();
        return;
    }
    adc_range range = adcctrl_get_previous_range(actual_settings->input, actual_settings->range);
    if(range == actual_settings->range){
        unlock();
        return;
    }
    actual_settings->range = range;
    unlock();
}
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

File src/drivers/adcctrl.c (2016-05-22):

/*
 * adcctrl.c
 *
 * Copyright (c) 2015, Diego F. Asanza. All rights reserved.
 *
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
 * Created on July 15, 2015, 10:39 PM
 */

/* This file generates the integration sequences which are sended to analog
 * multiplexer in multimeter.
 * They where copied from another working Keithley 199.
 * (c) 2014 Diego F. Asanza
 */

#include <stdint.h>
#include <stddef.h>
#include <assert.h>
#include <diag.h>
#include "adcctrl.h"

struct hal_adc_integration_sequence_t {
    uint32_t actual_value;
    uint32_t size;
    const uint32_t* mux_values;
};

#define START_SEQUENCE(seq_name) static const uint32_t seq_name##__[]=

#define END_SEQUENCE(seq_name) ; static adc_control_sequence seq_name = { \
                                            .actual_value = 0, \
                                            .size = sizeof(seq_name##__), \
                                            .mux_values = seq_name##__};

START_SEQUENCE(seq_300mV)
{
    0x01BFE292, 0x01BFE29A, 0x01FFE29A, /* preset */
    0x01FFE29D, 0x01FFE29C, 0x01BFE29A, /* signal */
    0x11BFE292, 0x11FFE292, /* preset */
    0x11FFE295, 0x11FFE294, 0x11BFE292, /* signal zero */
    0x41BFE292, /* preset */
    0x41BFE295, 0x41BFE294, 0x41BFE252, /* zero */
    0x41BFE255, 0x41BFE254, 0x41BFE252 /* ref */
}
END_SEQUENCE(seq_300mV)

START_SEQUENCE(seq_3V)
{
    0x01BFE292, 0x01BFE29A, /* preset */
    0x01BFE29D, 0x01BFE29C, 0x01BFE29A, /* signal */
    0x11BFE292, /* preset */
    0x11BFE295, 0x11BFE294, 0x41BFE292, /* signal zero */
    0x41BFE295, 0x41BFE294, 0x41BFE252, /* zero */
    0x41BFE255, 0x41BFE254, 0x41BFE252 /* ref */
}
END_SEQUENCE(seq_3V)

START_SEQUENCE(seq_30V)
{
    0x29BFE092, /* preset */
    0x29BFE095, 0x29BFE094, 0x08BFE092, /* signal */
    0x08BFE095, 0x08BFE094, 0x49BFE092, /* signal zero */
    0x49BFE095, 0x49BFE094, 0x49BFE052, /* zero */
    0x49BFE055, 0x49BFE054, 0x49BFE052 /* ref */
}
END_SEQUENCE(seq_30V)

START_SEQUENCE(seq_300V)
{
    0x25BFE092, /* preset */
    0x25BFE095, 0x25BFE094, 0x15BFE092, /* signal */
    0x15BFE095, 0x15BFE094, 0x45BFE092, /* signal zero */
    0x45BFE095, 0x45BFE094, 0x45BFE052, /* zero */
    0x45BFE055, 0x45BFE054, 0x45BFE052 /* ref */
}
END_SEQUENCE(seq_300V)

START_SEQUENCE(seq_300mVAC)
{
    0xCD1FECD5, 0xCD1FECD4, 0xCD1FECD2, /* signal */
    0xCD3FEC96, /* preset */
    0xCD3FEC95, 0xCD3FEC94, 0xCD3F1CD2, /* zero */
    0xCD3FEC96, /* preset */
    0xCD3FEC95, 0xCD3FEC94, 0xCD3F1CD2, /* zero */
    0xCD3FEC56, /* preset */
    0xCD3FEC55, 0xCD3FEC54, 0xCD1FECD2, /* ref */
}
END_SEQUENCE(seq_300mVAC)

START_SEQUENCE(seq_3VAC)
{
    0xCD9DCCD5, 0xCD9DCCD4, 0xCD9DCCD2, /* signal */
    0xCDBDCC96,
    0xCDBDCC95, 0xCDBDCC94, 0xCD9DCCD2, /* zero */
    0xCDBDCC96,
    0xCDBDCC95, 0xCDBDCC94, 0xCD9DCCD2, /* zero */
    0xCDBDCC56,
    0xCDBDCC55, 0xCDBDCC54, 0xCD9DCCD2 /* ref */
}
END_SEQUENCE(seq_3VAC)

START_SEQUENCE(seq_30VAC)
{
    0xCD9DF4D5, 0xCD9DF4D4, 0xCD9DF4D2, /* signal */
    0xCDBDF496,
    0xCDBDF495, 0xCDBDF494, 0xCD9DF4D2, /* zero */
    0xCDBDF496,
    0xCDBDF495, 0xCDBDF494, 0xCD9DF4D2, /* zero */
    0xCDBDF456,
    0xCDBDF455, 0xCDBDF454, 0xCD9DF4D2, /* ref */
}
END_SEQUENCE(seq_30VAC)

START_SEQUENCE(seq_300VAC)
{
    0xCD9DE4D5, 0xCD9DE4D4, 0xCD9DE4D2, /* signal */
    0xCDBDE496,
    0xCDBDE495, 0xCDBDE494, 0xCDBDE4D2,
    0xCDBDE496,
    0xCDBDE495, 0xCDBDE494, 0xCDBDE4D2,
    0xCDBDE456,
    0xCDBDE455, 0xCDBDE454, 0xCD9DE4D2
}
END_SEQUENCE(seq_300VAC)

START_SEQUENCE(seq_30mADC)
{
    0x4DE7E0D5, 0x4DE7E0D4, 0x4DE7E0D2,
    0x4DF7E096,
    0x4DF7E095, 0x4DF7E094, 0x4DE7E0D2,
    0x4DB7E096,
    0x4DB7E095, 0x4DB7E094, 0x4DE7E0D2,
    0x4DB7E056,
    0x4DB7E055, 0x4DB7E054, 0x4DE7E0D2,
}
END_SEQUENCE(seq_30mADC)

START_SEQUENCE(seq_3ADC)
{
    0x45E7E0D5, 0x45E7E0D4, 0x45E7E0D2,
    0x45B7E096,
    0x45B7E095, 0x45B7E094, 0x45E7E0D2,
    0x45F7E096,
    0x45F7E095, 0x45F7E094, 0x45E7E0D2,
    0x45B7E056,
    0x45B7E055, 0x45B7E054, 0x45E7E0D2,
}
END_SEQUENCE(seq_3ADC)

START_SEQUENCE(seq_30mAAC)
{
    0x4D15E8D5, 0x4D15E8D4, 0x4D15E8D2,
    0x4D35E896,
    0x4D35E895, 0x4D35E894, 0x4D15E8D2,
    0x4D35E896,
    0x4D35E895, 0x4D35E894, 0x4D15E8D2,
    0x4D35E856,
    0x4D35E855, 0x4D35E854, 0x4D15E8D2,
}
END_SEQUENCE(seq_30mAAC)


START_SEQUENCE(seq_3AAC)
{
    0x4515E8D5, 0x4515E8D4, 0x4515E8D2,
    0x4535E896,
    0x4535E895, 0x4535E894, 0x4515E8D2,
    0x4535E896,
    0x4535E895, 0x4535E894, 0x4515E8D2,
    0x4535E856,
    0x4535E855, 0x4535E854, 0x4515E8D2,
}
END_SEQUENCE(seq_3AAC)

START_SEQUENCE(seq_300Ohm)
{
    0x43FAE1D5, 0x43FAE1D4, 0x43FAE1D2, // SenseLo
    0x43FAE1D5, 0x43FAE1D4, 0x23BCE192, // Nothing
    0x23BCE195, 0x23BCE194, 0x03BEE192,
    0x42BEE1D2,
    0x42BEE1D5, 0x42BEE1D4, 0x03BEE19A,
    0x03FEE19A,
    0x03FEE19D, 0x03FEE19C, 0x43FAE1D2,
}
END_SEQUENCE(seq_300Ohm)

START_SEQUENCE(seq_3KOhm)
{
    0x43BAE1D5, 0x43BAE1D4, 0x43BAE1D2,
    0x43BAE1D5, 0x43BAE1D4, 0x23BCE192,
    0x23BCE195, 0x23BCE194, 0x03BEE192,
    0x42BEE1D2,
    0x42BEE1D5, 0x42BEE1D4, 0x03BEE19A,
    0x03BEE19D, 0x03BEE19C, 0x43BAE1D2,
}
END_SEQUENCE(seq_3KOhm)

START_SEQUENCE(seq_30KOhm)
{
    0x43BAE1D5, 0x43BAE1D4, 0x43BAE1D2,
    0x43BAE1D5, 0x43BAE1D4, 0x23BCE192,
    0x23BCE195, 0x23BCE194, 0x03BEE192,
    0x42BEE1D2,
    0x42BEE1D5, 0x42BEE1D4, 0x03BEE19A,
    0x03BEE19D, 0x03BEE19C, 0x43BAE1D2,
}END_SEQUENCE(seq_30KOhm)

START_SEQUENCE(seq_300KOhm){
    0xC7B1E1D5, 0xC7B1E1D4, 0xC7B1E1D2, 
    0xC7B1E1D5, 0xC7B1E1D4, 0xA7B5E192, 
    0xA7B5E195, 0xA7B5E194, 0x87B5E192, 
    0x97B5E192, 
    0x97B5E195, 0x97B5E194, 0x87B5E19A, 
    0x87B5E19D, 0x87B5E19C, 0xC7B1E1D2,     
}END_SEQUENCE(seq_300KOhm)

START_SEQUENCE(seq_3MegOhm){
    0xCBB1E1D5,0xCBB1E1D4,0xCBB1E1D2,
    0xCBB1E1D5,0xCBB1E1D4,0xABB5E192,
    0xABB5E195,0xABB5E194,0x8BB5E192,
    0x9BB5E192,
    0x9BB5E195,0x9BB5E194,0x8BB5E19A,
    0x8BB5E19D,0x8BB5E19C,0xCBB1E1D2,
}END_SEQUENCE(seq_3MegOhm)


//START_SEQUENCE(seq_30MegOhm){
//    
//}END_SEQUENCE(seq_30MegOhm)
//
//START_SEQUENCE(seq_300MegOhm){
//    
//}END_SEQUENCE(seq_300MegOhm)


static adc_control_sequence* get_vdc_seq(adc_range range);
static adc_control_sequence* get_vac_seq(adc_range range);
static adc_control_sequence* get_cdc_seq(adc_range range);
static adc_control_sequence* get_cac_seq(adc_range range);
static adc_control_sequence* get_res4w_seq(adc_range range);
//static hal_adc_sequence* get_vdc_seq(adc_range range);
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

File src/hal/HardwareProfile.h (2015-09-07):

/* 
 * File:   HardwareProfile.h
 * Author: diego
 *
 * Created on March 10, 2014, 9:15 PM
 */

#ifndef HARDWAREPROFILE_H
#define	HARDWAREPROFILE_H

#ifdef	__cplusplus
extern "C" {
#endif

#include <peripheral/ports.h>
#include <peripheral/pps.h>
#include <peripheral/timer.h>
#include <peripheral/ports.h>

#define PIC32_PERIPHERALBUS_FREQ 80000000UL
    
/* io definitions */
#define BRD_RED_LED         IOPORT_C, BIT_4
#define BRD_GREEN_LED       IOPORT_C, BIT_3
#define BRD_AUX_LED         IOPORT_B, BIT_4
#define DEBUG_PIN_0         IOPORT_A, BIT_9
    
#define BUZZER              IOPORT_G, BIT_9
    
#define I2C_SDA             IOPORT_G, BIT_3
#define I2C_SCL             IOPORT_G, BIT_2

/* map hal uarts to real uarts */
#define HAL_UART_COUNT        1   /**< Number of enabled uarts */
//#define HAL_UART_1          UART1
//#define HAL_UART_2          UART2
#define HAL_UART_3            UART3 /**< UART 3 enabled */
//#define HAL_UART_4          UART4
#define HAL_UART_5            UART5

#if defined HAL_UART_1
#error "define pps for uart 1"
#endif
#if defined HAL_UART_2
#error "define pps for uart 2"
#endif
#if defined HAL_UART_3
#define CONFIGURE_UART3_PPS() do{ \
        PPSInput(2,U3RX,RPB3); \
        PPSOutput(1,RPB5,U3TX); \
        PORTSetPinsDigitalIn(IOPORT_B,BIT_3);\
        PORTSetPinsDigitalOut(IOPORT_B, BIT_5); }while(0)
#endif
#if defined HAL_UART_4
#error "define pps for uart 4"
#endif
    
#if defined HAL_UART_5
#define CONFIGURE_UART5_PPS() do{ \
        PPSInput(4,U5RX,RPF13); \
        PPSOutput(3,RPF12,U5TX); \
        PORTSetPinsDigitalOut(IOPORT_F, BIT_12); \
        PORTSetPinsDigitalIn(IOPORT_F,BIT_13);\
        }while(0)  
#endif
    


/* Configure hardware counter used for read adc value */
#define HW_32BIT_COUNTER_SET_INPUT()do{ \
            PPSInput(3,T4CK,RPE3); \
            PORTSetPinsDigitalIn(KMM_COUNT); }while(0)

#define HW_32BIT_COUNTER_START( counter_period ) do{ \
    OpenTimer4(T4_ON|T4_IDLE_CON \
            |T4_GATE_OFF|T4_PS_1_1  \
            |T4_32BIT_MODE_ON|T4_SOURCE_EXT, counter_period ); \
    }while(0)

/**@brief Macro to clear hardware errors in UART Module */
#define _clroverrun(value) U##value##STAbits.OERR = 0
/**@brief Clear hardware errors from uart module */

#define UARTClearOverrunError(module_id) do{ \
        if(module_id == UART1) _clroverrun(1);\
        if(module_id == UART2) _clroverrun(2);\
        if(module_id == UART3) _clroverrun(3);\
        if(module_id == UART4) _clroverrun(4);\
        if(module_id == UART5)  _clroverrun(5);\
}while(0)
    
#define HW_32BIT_COUNTER_RESTART() WriteTimer4(0)

#define HW_32BIT_COUNTER_READ() ReadTimer4()

/* KMM Interface definitions */
#define KMM_CLK         IOPORT_F, BIT_6
#define KMM_DATA        IOPORT_F, BIT_8
#define KMM_STRB        IOPORT_G, BIT_1
#define KMM_COUNT       IOPORT_E, BIT_3

/* LCD Display */
#define DISPLAY_PORT    IOPORT_D
#define seg_a   BIT_5
#define seg_b   BIT_1
#define seg_c   BIT_3
#define seg_d   BIT_13
#define seg_e   BIT_2
#define seg_f   BIT_4
#define seg_g   BIT_6
#define seg_h   BIT_11
#define seg_i   BIT_10
#define seg_j   BIT_9
#define seg_k   BIT_8
#define seg_l   BIT_12
#define seg_m   BIT_7
#define seg_n   BIT_15 
#define seg_dp  BIT_14
    
#define dclk    IOPORT_G, BIT_6
#define ddata   IOPORT_C, BIT_1

/*EEPROM SUBSYSTEM*/
#define HAL_I2C_BUS      I2C1    /**< I2C module on chip */
#define HAL_I2C_CONFIG   I2C_ENABLE_SLAVE_CLOCK_STRETCHING|I2C_ENABLE_HIGH_SPEED /**< eeprom configuration*/

#define HAL_EEPROM_ADDRESS      0x50    /**< I2C address for the eeprom */
#define HAL_TEMPSENS_ADDRESS    0x48    /**< I2C address for temperature sensor */
#define HAL_I2C_FREQ            400000  /**< I2C bus frequency */
#define HAL_EEPROM_SIZE         0x8000  /**< EEPROM size in bytes */
#define HAL_EEPROM_PAGE_SIZE    64      /**< EEPROM page size in bytes */


    /* keyboard */
#define HAL_KYB_S0  IOPORT_G, BIT_0
#define HAL_KYB_S1  IOPORT_F, BIT_0
#define HAL_KYB_S2  IOPORT_G, BIT_14

#ifdef	__cplusplus
}
#endif

#endif	/* HARDWAREPROFILE_H */

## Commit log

2014-09-18 new interface to adc, now send hardcoded sequences directly
2014-09-18 voltage AC and DC working
2014-09-26 Adding files wrongly left out on last commit
    [KeithleyUpgrade.sch]
2014-10-03 refactoring the adc interface
2014-10-03 refactoring adc interface
2014-10-04 pressing the volt button two times does not cause changes between ac and dc modes anymore.
2014-12-25 adding tdd files
    [KeithleyUpgrade0.kicad_pcb, KeithleyUpgrade1.kicad_pcb]
2014-12-27 added ringbuffer to uart
2015-01-16 using os for uart send and receive functions
2015-01-17 uart module new implemented
2015-01-19 implementing i2c
    [KeithleyUpgrade.sch]
2015-01-19 i2c basics working
2015-01-22 fixed cristal footprint
    [KeithleyUpgrade.kicad_pcb, KeithleyUpgrade.sch]
2015-01-23 added driver for temp sensor
2015-01-23 refactor: moving timer to hal
2015-01-25 refactor adc interface
2015-05-26 update uart module
2015-05-30 fixing uart issues
2015-07-14 fixing format
    [KeithleyUpgrade.sch]
2015-07-14 fix: core timer interrupt is not being updated
    [dispkyb.c, hal_timer.c, main.c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]
2015-07-14 fix: keyboard now return key event if key was pressed.
    [dispkyb.c]
2015-07-14 fix: update keyboard repetition frequency
    [dispkyb.c]
2015-07-15 only print git hash into version string for better display
2015-07-16 refactoring settings and calibration values
    #
    #
2015-07-16 get an unique id for each supported hardware configuration. Useful to save and restore calibration values, as there is one calibration value for each hardware configuration
2015-07-17 fix: fix eeprom read nack. feat: return KEY_NONE when key released.
    [dispkyb.c, eeprom.c]
2015-07-19 fix: range up and down
    [adcctrl.c, disfmt.c, hal_sys.c]
2015-07-21 fix error printing double
2015-08-23 task switching seems to work
2015-08-24 quick and dirty task switching
2015-08-25 fix: bad scan key due to buggy highlight digit code Signed-off-by:Diego F. Asanza <f.asanza@gmail.com>
    [dispkyb.c]
2015-08-25 fix: evt clear not working due to false conditional. we wait until all data is received from queue. Signed-off-by:Diego F. Asanza <f.asanza@gmail.com>
    [dispkyb.c]
2015-08-25 fix: single adc calls didnt work because strobe was being continuously sended. Signed-off-by:Diego F. Asanza <f.asanza@gmail.com>
    [hal_adc.c]
2015-08-25 input calibration values working
2015-08-26 add scl and sda pin defines Signed-off-by:Diego F. Asanza <f.asanza@gmail.com>
2015-08-26 fix: wrong sequence existence comparisson. Signed-off-by:Diego F. Asanza <f.asanza@gmail.com>
    [adcctrl.c]
2015-08-26 calibration code working
2015-08-26 working dc-voltage and dc-current. Working calibration code
2015-08-26 fix compiler warnings. Activate no-short-double option
    [adc.c, adcctrl.c, disfmt.c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]
2015-08-27 added double printing functions
2015-08-27 fix: substitute formating functions with custom functions. (xc32 printf for 64bit double are broken).
    [disfmt.c]
2015-08-27 fix calibration issues with long double
    [disfmt.c, main.c, task_calibration.c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]
2015-08-27 fix calibration issues
2015-08-28 change wait for working. filter size is now 100 measurements. Signed-off-by:Diego F. Asanza <f.asanza@gmail.com>
2015-08-29 implemented temperature measurement by internal sensor
2015-08-29 fixed temperature code
2015-08-29 fix bug hang when pressing the temperature button fast
    [disfmt.c, system.c]
2015-08-29 integrate scpi. implement idn command
    [KeithleyUpgrade.kicad_pcb]
2015-08-30 fix scpi print double
    [tskmgr.c]
2015-08-30 fix memory allocation error
    [hal_adc.c]
2015-08-30 fixed shift key behaviour
    [dispkyb.c, tskmgr.c]
2015-08-31 temperature does not autoranges
2015-09-06 fix bug on double to string conversion.
    [adcctrl.c, main.c]
2015-09-06 300Ohm resistance range seems to work. Noise on last digit.
    [adc.c, adcctrl.c, tskmgr.c]
2015-09-07 increase i2c frequency. Set default calibration values for temperature
2015-09-13 fix: calibration not being restored when using autorange
2015-09-13 updating schematic
    [KeithleyUpgrade.sch, scanner.sch]
2015-12-07 fix compilation issues
    [KeithleyUpgrade.dsn, KeithleyUpgrade.kicad_pcb, KeithleyUpgrade.sch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]
2015-12-07 fix some errors
    [frontdesign.fcstd, frontpanel.dsn, frontpanel.kicad_pcb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]
2016-01-06 adding frontpanel hw
    [frontdesign.fcstd, frontpanel.kicad_pcb]
2016-01-06 adding fp files
    [LedMatrix.fcstd, frontpanel.dxf]
2016-01-10 fixing task key behaviour
    [task_calibration.c, tskmgr.c]
2016-01-10 fix bad assert value
    [adc.c, settings.c]
2016-01-11 fix: eeprom needs reset after changing i2c from temperature sensor to eeprom
    [eeprom.c, hal_i2c.c, settings.c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]
2016-01-16 fix: task suspend resume when changing settings
    [adc.c, settings.c, system.c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]
2016-01-16 fix: hangup after repeated volt settings selection
    [tskmgr.c]
2016-01-16 fix: fix resistance measurement for 300k and 3M scales
    [adc.c, settings.c, task_calibration.c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]
2016-02-07 update files
    [frontpanel.dxf, frontpanel.kicad_pcb, frontpanel.sch]
2016-05-21 added a couple of nets to the pcb
    [KeithleyUpgrade.kicad_pcb]
2016-05-22 addedd documentation@
    [KeithleyUpgrade.kicad_pcb, KeithleyUpgrade.sch]
2016-06-26 update documentation
    [KeithleyUpgrade.sch]
2018-06-10 add some documentation
    [decoding.ods, pic32_timing_analyisis.csv, pic32_timing_analyisis_4MHZ.csv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]
